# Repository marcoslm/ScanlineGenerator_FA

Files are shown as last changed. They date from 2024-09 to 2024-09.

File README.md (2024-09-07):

# VGA Scanline Generator

Este proyecto fue diseñado en 2015 para **Factory Arcade** ([sitio web](https://www.factoryarcade.es/)), una empresa dedicada a la restauración y fabricación de máquinas recreativas arcade. El objetivo es simular scanlines CRT en pantallas LCD. A diferencia de otros "slg" similares, este modelo soporta resoluciones **SVGA/XGA**.

IMG-20151215-WA0005

## Características

- Alimentación desde el conector VGA de entrada o mediante el conector JP1 con una alimentación estabilizada de 5V DC.
- Soporta resoluciones VGA, SVGA y XGA, proporcionando una simulación fiel de las líneas de barrido.
- Sin lag de ninguna clase.

En este repositorio encontrarás los archivos de diseño en formato Eagle y los archivos Gerber listos para enviar a fabricación.

## Conectores y Jumpers de Configuración

| Conector/Jumper | Nombre | Descripción |
|---|---|---|
| CON1 | VGA OUT | Salida VGA hacia el monitor |
| CON2 | VGA IN | Entrada VGA desde la placa o PC arcade |
| JP1 | +5V | Alimentación opcional de 5V DC |
| JP2 | ON/OFF | 1-2: scanlines activas, 2-3: scanlines desactivadas |
| JP3 | POLARITY | Polaridad de las señales de sincronización (según entrada) |
| JP4 | WIDTH | Selección del grosor del scanline (fino o grueso) |
| JP5 | EVEN/ODD | Selección de scanlines en líneas pares o impares del trazado |

## Solución de Problemas

Si al conectarlo todo tienes problemas de imagen:
- Verifica la configuración de la polaridad (JP3).
- Es posible que la señal de 5V desde el conector VGA IN sea insuficiente o inexistente. En ese caso, puedes alimentar la placa directamente a través de JP1 con 5V DC regulados.

## Rework en la Versión 1a

En esta primera versión del diseño, hay un pequeño error debido a la falta de una resistencia pull-down en el jumper JP2. Para corregirlo, deberás soldar una resistencia de 10k de forma manual.

IMG-20160426-WA0000
IMG-20160426-WA0001
IMAG3637

## Bill of Materials (BOM)

Puedes consultar la lista de materiales completa en el archivo [`BOM.md`](./BOM.md).

## Licencia

Este proyecto se distribuye bajo la licencia **Creative Commons Attribution-NonCommercial 4.0 International (CC BY-NC 4.0)**. Se publica con el consentimiento de **Factory Arcade** y eres libre de utilizar, modificar y distribuir el trabajo, siempre otorgando el crédito adecuado y no está permitido el uso comercial del proyecto. Consulta el archivo [LICENSE](./LICENSE) para más detalles.

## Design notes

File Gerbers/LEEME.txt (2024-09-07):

 ARCHIVO        CAPA                    FORMATO
-------------- ----------------------- ----------------
ScanGen10.GTL	Top Copper       	GERBER_RS274X
ScanGen10.GBL	Bottom Copper    	GERBER_RS274X
ScanGen10.GTS	Top Soldermask   	GERBER_RS274X
ScanGen10.GBS	Bottom Soldermask	GERBER_RS274X
ScanGen10.GTO	Top Silkscreen   	GERBER_RS274X
ScanGen10.TXT	Drills           	EXCELLON

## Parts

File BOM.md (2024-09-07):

# Bill of Materials (BOM)

| Qty | Value | Device | Package  | Parts  | Description |
|-----|---|---|---|---|---|
| 1 | +5V - | 1X2-3.5MM | 1X2-3.5MM| JP1 | 3.5mm Terminal block |
| 2 | 10K | R-EU_0204/7 | 0204/7 | R1, R2 | RESISTOR, European symbol |
| 2 | 1N4004  | 1N4004 | DO41-10  | D1, D2 | DIODE |
| 1 | 2N3904  | 2N3904 | TO92 | T1 | NPN TRANSISTOR |
| 1 | 74HC125N| 74HC125N | DIL14 | IC2 | Quad bus BUFFER, 3-state |
| 1 | 74LS74N | 74LS74N | DIL14 | IC1 | Dual D type positive edge triggered FLIP FLOP, preset and clear |
| 1 | EVEN/ODD| PINHD-1X3 | 1X03 | JP5 | PIN HEADER |
| 1 | ON / OFF| PINHD-1X3 | 1X03 | JP2 | PIN HEADER |
| 1 | POLARITY| PINHD-1X3 | 1X03 | JP3 | PIN HEADER |
| 1 | VGA IN  | HF15H | HDF15H | CON2 | SUB-D |
| 1 | VGA OUT | HF15H | HDF15H | CON1 | SUB-D |
| 1 | WIDTH | PINHD-1X3 | 1X03 | JP4 | PIN HEADER |

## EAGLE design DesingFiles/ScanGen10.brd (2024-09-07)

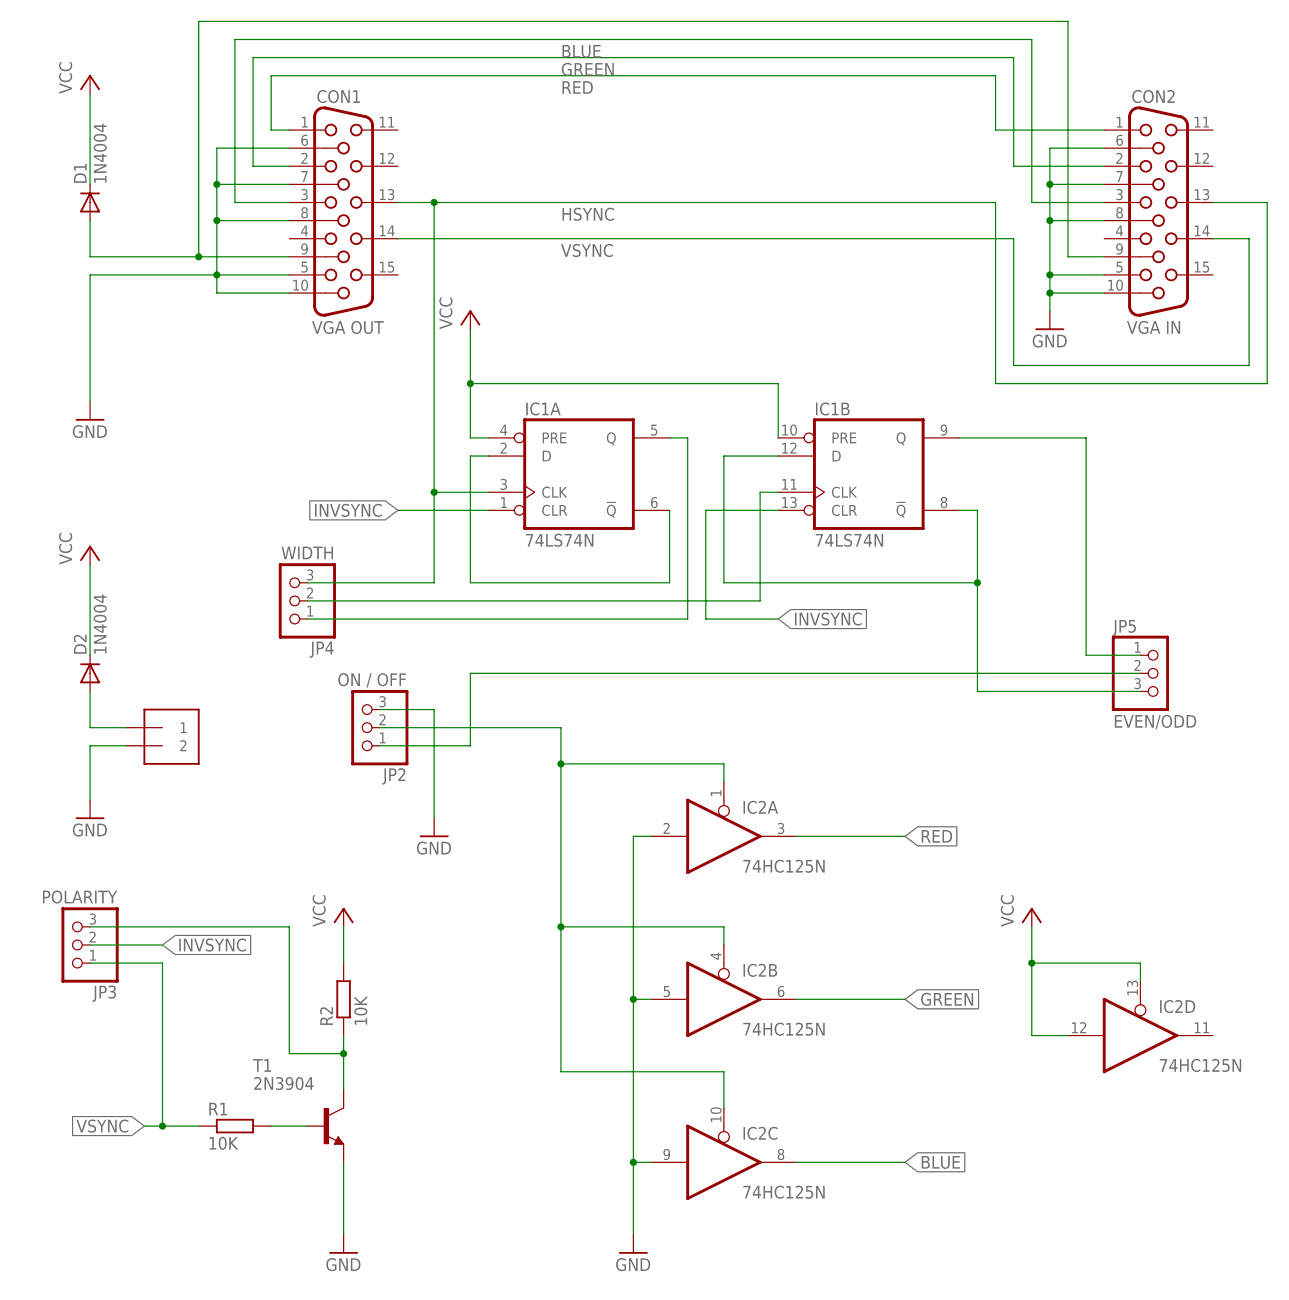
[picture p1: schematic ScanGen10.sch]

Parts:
CON1: VGA OUT; HDF15H
CON2: VGA IN; HDF15H
D1, D2: 1N4004; DO41-10
IC1: 74LS74N; DIL14
IC2: 74HC125N; DIL14
JP1: + 5V -; 1X2-3.5MM
JP2: ON / OFF; 1X03
JP3: POLARITY; 1X03
JP4: WIDTH; 1X03
JP5: EVEN/ODD; 1X03
R1, R2: 10K; 0204/7
T1: 2N3904; TO92

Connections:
BLUE: CON1.3, CON2.3, IC2.8 (O)
GND: CON1.5, CON1.6, CON1.7, CON1.8, CON1.10, CON2.5, CON2.6, CON2.7, CON2.8, CON2.10, IC1.7 (GND), IC2.2 (I), IC2.5 (I), IC2.7 (GND), IC2.9 (I), JP1.2, JP2.3, T1.3 (E)
GREEN: CON1.2, CON2.2, IC2.6 (O)
HSYNC: CON1.13, CON2.13, IC1.3 (CLK), JP4.3
INVSYNC: IC1.1 (CLR), IC1.13 (CLR), JP3.2
unnamed: CON1.9, CON2.9, D1.A
unnamed: D2.A, JP1.1
unnamed: IC1.11 (CLK), JP4.2
unnamed: IC1.5 (Q), JP4.1
unnamed: IC1.2 (D), IC1.6 (!Q)
unnamed: IC1.8 (!Q), IC1.12 (D), JP5.3
unnamed: IC1.9 (Q), JP5.1
unnamed: IC2.1 (OE), IC2.4 (OE), IC2.10 (OE), JP2.2
unnamed: R1.2, T1.2 (B)
unnamed: JP3.3, R2.1, T1.1 (C)
unnamed: JP2.1, JP5.2
RED: CON1.1, CON2.1, IC2.3 (O)
VCC: D1.C, D2.C, IC1.4 (PRE), IC1.10 (PRE), IC1.14 (VCC), IC2.12 (I), IC2.13 (OE), IC2.14 (VCC), R2.2
VSYNC: CON1.14, CON2.14, JP3.1, R1.1

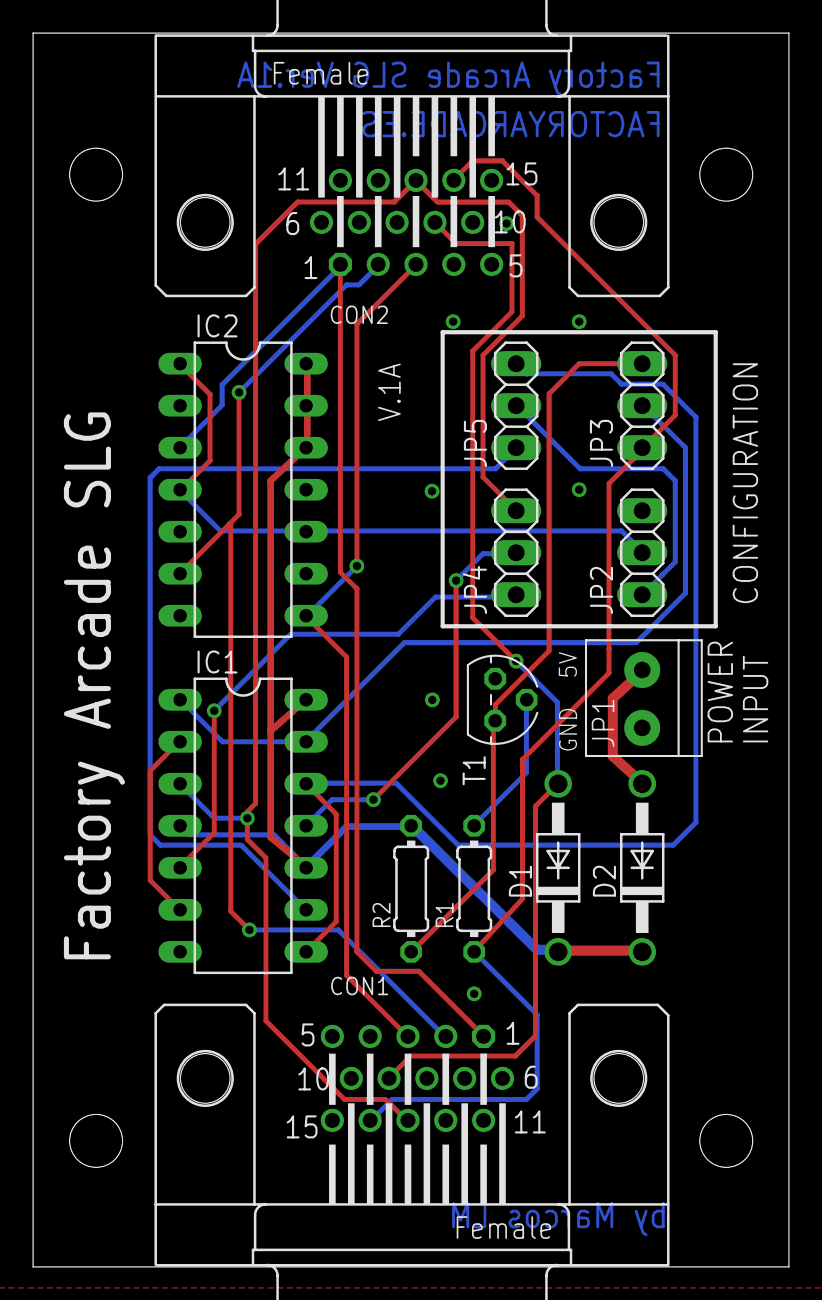
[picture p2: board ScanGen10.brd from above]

Board: 2 copper layers, 45.7 x 74.6 mm, 14 parts (0 on the bottom side), 19 nets.

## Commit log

2024-09-07 Commit inicial
    [ScanGen10.brd, ScanGen10.sch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]
2024-09-07 BOM en formato markdown
